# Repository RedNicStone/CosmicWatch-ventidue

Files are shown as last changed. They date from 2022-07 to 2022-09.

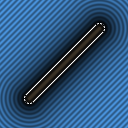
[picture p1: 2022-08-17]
software/arduino/cmake-build-debug/feh_078198_000001_demo.bmp

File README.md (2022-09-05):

<p align="center">
    CosmicWatch logo
    CosmicWatch logo
</p>

---
[]()
[]()
[]()

# CosmicWatch Ventidue
Continuation of the original CosmicWatch project by Spencer featuring many improvements and additions.

## What's new?
CosmicWatch Ventidue's new features are plentiful so here is a quick summary:
- Flexible design that allows connecting either one or two detectors
- Built in on-silicon coincidence detection between the two modules
  - Time resolutions from 5ns down to just 1ns [cooling required]
- Powerful Teensy 4.1 microcontroller
- Full color 1.5" OLED display with great user interface
  - Rotary encoder for easy navigation
  - Buzzer for audible counting and interface feedback
  - Custom rendering library for maximum performance
- Optional solder-free support for multiple prebuilt sensor modules
  - GPS, Pressure, Humidity, Temperature and RTC supported
- Built in Ethernet module for intra & intercommunication
- Improved mechanical stability and 3D printed casing
- Interrupt driven software architecture for accurate counting and a responsive user interface

## Hardware []()
A first prototype has been produced and tested. 
We are currently busy on fabricating a newer board that will be tested as soon as finished.  
There are plans to provide a kit with a pre-assembled board for purchase once hardware development has sized.

### Overview
> todo

## Software []()
Software is currently undergoing heavy development and is only barely runnable.  
If you do want to take a look [check this folder](software/arduino).

The following modules have been written so far:
- Custom rendering pipeline
- OLED driver [Needs push to support DMA]
- On-chip coincidence detection
- Example for testing peripherals

The following modules still need tending:
- True type font rendering
- UI and windowing system
- Data acquisition and storage
- Ethernet communication

**Any help is much appreciated!**

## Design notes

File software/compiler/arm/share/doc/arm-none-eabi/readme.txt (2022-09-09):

Arm GNU Toolchain 12.2.mpacbti-bet1
GNU toolchain for the Arm architecture
GCC Version: 12.2

For updated content, see the release note for the relevant release, on:
https://developer.arm.com/tools-and-software/open-source-software/developer-tools/gnu-toolchain/downloads

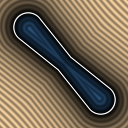
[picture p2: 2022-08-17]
software/arduino/demo.bmp

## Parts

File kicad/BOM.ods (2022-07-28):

Main PCB
Quantity | Name | Value / Part number | Digikey part number
1 | 2x Two way shottky diode, SMD | BAS70XY | 1727-2168-1-ND
1 | 3.6V Linear voltage regulator, SMD | TCR2EF | TCR2EF33LM(CTCT-ND
1 | Active switching boost voltage regulator, SMD | MAX5025 | MAX5026EUT+TCT-ND
8 | Capacitor, SMD, non polarized | 1uF
1 | Capacitor, SMD, non polarized | 10nF
1 | Capacitor, SMD, non polarized | 0.1uF
1 | Inductor, SMD | 47uH / LQH32CN470K53L | 490-4063-1-ND
1 | JST-PH connector, 1x02 pins, 2mm pitch | B2B-PH-K-S(LF)(SN) | 455-1704-ND
1 | Piezo buzzer | PS1240P02BT | 445-2525-1-ND
1 | Pin header, 1x05 pins, 2.45mm pitch | 77311-102-05LF | 609-77311-102-05LF-ND
1 | Pin socket, 1x04 pins, 2.45mm pitch
3 | Pin socket, 1x05 pins, 2.45mm pitch
3 | Pin socket, 1x07 pins, 2.45mm pitch
1 | Pin socket, 1x06 pins, 2.45mm pitch
2 | Resistor, SMD | 10k
3 | Resistor, SMD | 1k
1 | Resistor, SMD | 0
1 | Resistor, SMD | 6.65k
1 | Resistor, SMD | 147k
1 | Resistor, SMD | 100
1 | RJ45 connector with LED indicators | J1B12111CCD | 1278-1052-ND
1 | Shottky diode, SMD | MBR0540 | MBR0540CT-ND
1 | Tennsy 4.1 Micro controller | DEV-16771 | 1568-DEV-16771-ND
SiPM
Quantity | Name | Value / Part number | Digikey part number
1 | 2x Two way shottky diode, SMD | BAS70XY | 1727-2168-1-ND
1 | Capacitor, SMD, non polarized | 1uF
4 | Capacitor, SMD, non polarized | 10nF
2 | Capacitor, SMD, non polarized | 0.1uF
2 | Capacitor, SMD, non polarized | 13pF
2 | Capacitor, SMD, non polarized | 2nF
1 | Pin header, 1x05 pins, SMD, 2.45mm pitch | TSM-105-01-F-SV | TSM-105-01-F-SV-ND
1 | Pin header, 1x07 pins, SMD, 2.45mm pitch | TSM-107-01-L-SV | 2031-TSM-107-01-L-SV-ND
2 | Rail to Rail operational amplifier, SMD | LT1807 | 505-LT1807CMS8#PBF-ND
2 | Resistor, SMD | 50
2 | Resistor, SMD | 150
4 | Resistor, SMD | 100k
2 | Resistor, SMD | 10k
1 | Resistor, SMD | 1k
1 | Resistor, SMD | 10
1 | Resistor, SMD | 2.32k
4 | uFl socket, SMD, vertical | CONUFL001-SMD-T | CONUFL001-SMD-TCT-ND
1 | Silicon cascading photomultiplier | SiPM_MICRORB−60035−MLP | MICROFC-60035-SMT-TR1OS-ND
To order
Quantity | Name | Part number | Digikey part number
3 | 2x Two way shottky diode, SMD | BAS70XY | 1727-2168-1-ND
1 | Piezo buzzer | PS1240P02BT | 445-2525-1-ND
1 | RJ45 connector with LED indicators | J1B12111CCD | 1278-1052-ND
1 | JST-PH connector, 1x02 pins, 2mm pitch | B2B-PH-K-S(LF)(SN) | 455-1704-ND
1 | Pin headers, SMD, 2.54mm pitch | GBC36SABN-M30 | S1033E-36-ND
1 | Pin headers, 2.54mm pitch | PBC36SAAN | S1011E-36-ND
2 | Pin sockets, 2.54mm pitch | SSA-132-S-G | SAM1121-32-ND
1 | Mini GPS PA1010D | 4415 | 1528-4415-ND
4 | Capacitor, SMD, 10nF, 30V
5 | Capacitor, SMD, 1uF, 30V

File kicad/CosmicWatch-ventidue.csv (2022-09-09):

Source: | /home/niels/CLionProjects/CosmicWatch-ventidue/kicad/CosmicWatch-ventidue.kicad_sch
Date: | Wed 07 Sep 2022 05:16:37 PM CEST
Tool: | Eeschema 6.0.7-1.fc36
Generator: | /usr/share/kicad/plugins/bom_csv_grouped_by_value.py
Component Count: | 117
Individual Components:
Item | Qty | Reference(s) | Value | LibPart | Footprint | Datasheet | LCSC | MANUFACTURER | MAXIMUM_PACKAGE_HEIGHT | PARTREV | STANDARD
 |  | BT401 | Battery_Cell | Device:Battery_Cell | Connector_Molex:Molex_PicoBlade_53047-0210_1x02_P1.25mm_Vertical | ~ | C518987
 |  | BZ101 | Buzzer | Device:Buzzer | Buzzer_Beeper:Buzzer_TDK_PS1240P02BT_D12.2mm_H6.5mm | ~ | C76871
 |  | C201 | 10nF | Device:C | Capacitor_SMD:C_0805_2012Metric_Pad1.18x1.45mm_HandSolder | ~ | C24666
 |  | C202 | 0.1uF | Device:C | Capacitor_SMD:C_0805_2012Metric_Pad1.18x1.45mm_HandSolder | ~ | C89258
 |  | C203 | 1uF | Device:C | Capacitor_SMD:C_0805_2012Metric_Pad1.18x1.45mm_HandSolder | ~ | C89190
 |  | C204 | 10nF | Device:C | Capacitor_SMD:C_0805_2012Metric_Pad1.18x1.45mm_HandSolder | ~ | C24666
 |  | C205 | 10nF | Device:C | Capacitor_SMD:C_0805_2012Metric_Pad1.18x1.45mm_HandSolder | ~ | C24666
 |  | C206 | 0.1uF | Device:C | Capacitor_SMD:C_0805_2012Metric_Pad1.18x1.45mm_HandSolder | ~ | C89258
 |  | C207 | 10nF | Device:C | Capacitor_SMD:C_0805_2012Metric_Pad1.18x1.45mm_HandSolder | ~ | C24666
 |  | C208 | 13pF | Device:C | Capacitor_SMD:C_0805_2012Metric_Pad1.18x1.45mm_HandSolder | ~ | C501858
 |  | C209 | 13pF | Device:C | Capacitor_SMD:C_0805_2012Metric_Pad1.18x1.45mm_HandSolder | ~ | C501858
 |  | C210 | 1uF | Device:C | Capacitor_SMD:C_0805_2012Metric_Pad1.18x1.45mm_HandSolder | ~ | C89190
 |  | C211 | 2nF | Device:C | Capacitor_SMD:C_0805_2012Metric_Pad1.18x1.45mm_HandSolder | ~ | C51574
 |  | C212 | 2nF | Device:C | Capacitor_SMD:C_0805_2012Metric_Pad1.18x1.45mm_HandSolder | ~ | C51574
 |  | C301 | 10nF | Device:C | Capacitor_SMD:C_0805_2012Metric_Pad1.18x1.45mm_HandSolder | ~ | C24666
 |  | C302 | 0.1uF | Device:C | Capacitor_SMD:C_0805_2012Metric_Pad1.18x1.45mm_HandSolder | ~ | C89258
 |  | C303 | 1uF | Device:C | Capacitor_SMD:C_0805_2012Metric_Pad1.18x1.45mm_HandSolder | ~ | C89190
 |  | C304 | 10nF | Device:C | Capacitor_SMD:C_0805_2012Metric_Pad1.18x1.45mm_HandSolder | ~ | C24666
 |  | C305 | 10nF | Device:C | Capacitor_SMD:C_0805_2012Metric_Pad1.18x1.45mm_HandSolder | ~ | C24666
 |  | C306 | 0.1uF | Device:C | Capacitor_SMD:C_0805_2012Metric_Pad1.18x1.45mm_HandSolder | ~ | C89258
 |  | C307 | 10nF | Device:C | Capacitor_SMD:C_0805_2012Metric_Pad1.18x1.45mm_HandSolder | ~ | C24666
 |  | C308 | 13pF | Device:C | Capacitor_SMD:C_0805_2012Metric_Pad1.18x1.45mm_HandSolder | ~ | C501858
 |  | C309 | 13pF | Device:C | Capacitor_SMD:C_0805_2012Metric_Pad1.18x1.45mm_HandSolder | ~ | C501858
 |  | C310 | 1uF | Device:C | Capacitor_SMD:C_0805_2012Metric_Pad1.18x1.45mm_HandSolder | ~ | C89190
 |  | C311 | 2nF | Device:C | Capacitor_SMD:C_0805_2012Metric_Pad1.18x1.45mm_HandSolder | ~ | C51574
 |  | C312 | 2nF | Device:C | Capacitor_SMD:C_0805_2012Metric_Pad1.18x1.45mm_HandSolder | ~ | C51574
 |  | C401 | 1uF | Device:C | Capacitor_SMD:C_0805_2012Metric_Pad1.18x1.45mm_HandSolder | ~ | C89190
 |  | C402 | 1uF | Device:C | Capacitor_SMD:C_0805_2012Metric_Pad1.18x1.45mm_HandSolder | ~ | C89190
 |  | C403 | 47uF | Device:C | Capacitor_SMD:C_0805_2012Metric_Pad1.18x1.45mm_HandSolder | ~ | C89190
 |  | C404 | 1uF | Device:C | Capacitor_SMD:C_0805_2012Metric_Pad1.18x1.45mm_HandSolder | ~ | C89190
 |  | C405 | 1uF, 50V | Device:C | Capacitor_SMD:C_0805_2012Metric_Pad1.18x1.45mm_HandSolder | ~ | C111768
 |  | C406 | 1uF, 50V | Device:C | Capacitor_SMD:C_0805_2012Metric_Pad1.18x1.45mm_HandSolder | ~ | C111768
 |  | C407 | 10nF, 50V | Device:C | Capacitor_SMD:C_0805_2012Metric_Pad1.18x1.45mm_HandSolder | ~ | C83170
 |  | C408 | 100nF | Device:C | Capacitor_SMD:C_0805_2012Metric_Pad1.18x1.45mm_HandSolder | ~ | C89190
 |  | C501 | 0.1uF | Device:C | Capacitor_SMD:C_0805_2012Metric_Pad1.18x1.45mm_HandSolder | ~ | C89258
 |  | D101 | BAS70XY | CosmicWatchPro:BAS70XY | CosmicWatchPro:SOT-666 | ~ | C73592
 |  | D201 | SiPM_MICRORB−60035−MLP | CosmicWatchPro:SiPM_MICRORB−10035−MLP | CosmicWatchPro:SiPM_MICROFC-60035-SMT-HANDSOLDER | ~ | C905854
 |  | D202 | BAS70XY | CosmicWatchPro:BAS70XY | CosmicWatchPro:SOT-666 | ~ | C73592
 |  | D301 | SiPM_MICRORB−60035−MLP | CosmicWatchPro:SiPM_MICRORB−10035−MLP | CosmicWatchPro:SiPM_MICROFC-60035-SMT-HANDSOLDER | ~ | C905854
 |  | D302 | BAS70XY | CosmicWatchPro:BAS70XY | CosmicWatchPro:SOT-666 | ~ | C73592
 |  | D401 | D_Schottky | Device:D_Schottky | Diode_SMD:D_SOD-123 | ~ | C1884550
 |  | J101 | Conn_01x05 | Connector_Generic:Conn_01x05 | Connector_PinHeader_2.54mm:PinHeader_1x05_P2.54mm_Vertical_SMD_Pin1Right | ~
 |  | J102 | Conn_01x07 | Connector_Generic:Conn_01x07 | Connector_PinHeader_2.54mm:PinHeader_1x07_P2.54mm_Vertical_SMD_Pin1Right | ~
 |  | J103 | Conn_01x05 | Connector_Generic:Conn_01x05 | Connector_PinHeader_2.54mm:PinHeader_1x05_P2.54mm_Vertical_SMD_Pin1Right | ~
 |  | J104 | Conn_01x07 | Connector_Generic:Conn_01x07 | Connector_PinHeader_2.54mm:PinHeader_1x07_P2.54mm_Vertical_SMD_Pin1Right | ~
 |  | J105 | Conn_01x05 | Connector_Generic:Conn_01x05 | Connector_PinSocket_2.54mm:PinSocket_1x05_P2.54mm_Vertical | ~
 |  | J106 | Conn_01x07 | Connector_Generic:Conn_01x07 | Connector_PinSocket_2.54mm:PinSocket_1x07_P2.54mm_Vertical | ~
 |  | J107 | Conn_01x05 | Connector_Generic:Conn_01x05 | Connector_PinSocket_2.54mm:PinSocket_1x05_P2.54mm_Vertical | ~
 |  | J108 | Conn_01x07 | Connector_Generic:Conn_01x07 | Connector_PinSocket_2.54mm:PinSocket_1x07_P2.54mm_Vertical | ~
 |  | J109 | BMP280 | Connector_Generic:Conn_01x04 | Connector_PinSocket_2.54mm:PinSocket_1x04_P2.54mm_Vertical | ~
 |  | J110 | Mini GPS | Connector_Generic:Conn_01x06 | Connector_PinSocket_2.54mm:PinSocket_1x06_P2.54mm_Vertical | ~
 |  | J111 | OLED | Connector_Generic:Conn_01x07 | Connector_PinSocket_2.54mm:PinSocket_1x07_P2.54mm_Vertical | ~
 |  | J112 | DS3231 | Connector_Generic:Conn_01x05 | Connector_PinHeader_2.54mm:PinHeader_1x05_P2.54mm_Vertical | ~
 |  | J201 | Conn_SMA | CosmicWatchPro:Conn_SMA | Connector_Coaxial:U.FL_Molex_MCRF_73412-0110_Vertical | ~ | C88374
 |  | J202 | Conn_SMA | CosmicWatchPro:Conn_SMA | Connector_Coaxial:U.FL_Molex_MCRF_73412-0110_Vertical | ~ | C88374
 |  | J203 | Conn_SMA | CosmicWatchPro:Conn_SMA | Connector_Coaxial:U.FL_Molex_MCRF_73412-0110_Vertical | ~ | C88374
 |  | J204 | Conn_SMA | CosmicWatchPro:Conn_SMA | Connector_Coaxial:U.FL_Molex_MCRF_73412-0110_Vertical | ~ | C88374
 |  | J301 | Conn_SMA | CosmicWatchPro:Conn_SMA | Connector_Coaxial:U.FL_Molex_MCRF_73412-0110_Vertical | ~ | C88374
 |  | J302 | Conn_SMA | CosmicWatchPro:Conn_SMA | Connector_Coaxial:U.FL_Molex_MCRF_73412-0110_Vertical | ~ | C88374
 |  | J303 | Conn_SMA | CosmicWatchPro:Conn_SMA | Connector_Coaxial:U.FL_Molex_MCRF_73412-0110_Vertical | ~ | C88374
 |  | J304 | Conn_SMA | CosmicWatchPro:Conn_SMA | Connector_Coaxial:U.FL_Molex_MCRF_73412-0110_Vertical | ~ | C88374
 |  | J401 | Conn_01x02 | Connector_Generic:Conn_01x02 | Connector_JST:JST_PH_B2B-PH-K_1x02_P2.00mm_Vertical | ~ | C225240
 |  | L401 | 47uH | Device:L | Inductor_SMD:L_1210_3225Metric_Pad1.42x2.65mm_HandSolder | ~ | C113070
 |  | R102 | 1k | Device:R | Resistor_SMD:R_0805_2012Metric_Pad1.20x1.40mm_HandSolder | ~ | C17513
 |  | R105 | 10k | Device:R | Resistor_SMD:R_0805_2012Metric_Pad1.20x1.40mm_HandSolder | ~ | C17414
 |  | R106 | 10k | Device:R | Resistor_SMD:R_0805_2012Metric_Pad1.20x1.40mm_HandSolder | ~ | C17414
 |  | R201 | 50 | Device:R | Resistor_SMD:R_0805_2012Metric_Pad1.20x1.40mm_HandSolder | ~ | C2828807
 |  | R202 | 50 | Device:R | Resistor_SMD:R_0805_2012Metric_Pad1.20x1.40mm_HandSolder | ~ | C2828807
 |  | R203 | 10 | Device:R | Resistor_SMD:R_0805_2012Metric_Pad1.20x1.40mm_HandSolder | ~ | C96347
 |  | R204 | 150 | Device:R | Resistor_SMD:R_0805_2012Metric_Pad1.20x1.40mm_HandSolder | ~ | C17471
 |  | R205 | 2.32k | Device:R | Resistor_SMD:R_0805_2012Metric_Pad1.20x1.40mm_HandSolder | ~ | C17522
 |  | R206 | 10k | Device:R | Resistor_SMD:R_0805_2012Metric_Pad1.20x1.40mm_HandSolder | ~ | C17414
 |  | R207 | 150 | Device:R | Resistor_SMD:R_0805_2012Metric_Pad1.20x1.40mm_HandSolder | ~ | C17471
 |  | R208 | 1k | Device:R | Resistor_SMD:R_0805_2012Metric_Pad1.20x1.40mm_HandSolder | ~ | C17513
 |  | R209 | 100k | Device:R | Resistor_SMD:R_0805_2012Metric_Pad1.20x1.40mm_HandSolder | ~ | C149504
 |  | R210 | 10k | Device:R | Resistor_SMD:R_0805_2012Metric_Pad1.20x1.40mm_HandSolder | ~ | C17414
 |  | R211 | 100k | Device:R | Resistor_SMD:R_0805_2012Metric_Pad1.20x1.40mm_HandSolder | ~ | C149504
 |  | R212 | 100k | Device:R | Resistor_SMD:R_0805_2012Metric_Pad1.20x1.40mm_HandSolder | ~ | C149504
 |  | R213 | 100k | Device:R | Resistor_SMD:R_0805_2012Metric_Pad1.20x1.40mm_HandSolder | ~ | C149504
 |  | R301 | 50 | Device:R | Resistor_SMD:R_0805_2012Metric_Pad1.20x1.40mm_HandSolder | ~ | C2828807
 |  | R302 | 50 | Device:R | Resistor_SMD:R_0805_2012Metric_Pad1.20x1.40mm_HandSolder | ~ | C2828807
 |  | R303 | 10 | Device:R | Resistor_SMD:R_0805_2012Metric_Pad1.20x1.40mm_HandSolder | ~ | C96347
 |  | R304 | 150 | Device:R | Resistor_SMD:R_0805_2012Metric_Pad1.20x1.40mm_HandSolder | ~ | C17471
 |  | R305 | 2.32k | Device:R | Resistor_SMD:R_0805_2012Metric_Pad1.20x1.40mm_HandSolder | ~ | C17522
 |  | R306 | 10k | Device:R | Resistor_SMD:R_0805_2012Metric_Pad1.20x1.40mm_HandSolder | ~ | C17414
 |  | R307 | 150 | Device:R | Resistor_SMD:R_0805_2012Metric_Pad1.20x1.40mm_HandSolder | ~ | C17471
 |  | R308 | 1k | Device:R | Resistor_SMD:R_0805_2012Metric_Pad1.20x1.40mm_HandSolder | ~ | C17513
 |  | R309 | 100k | Device:R | Resistor_SMD:R_0805_2012Metric_Pad1.20x1.40mm_HandSolder | ~ | C149504
 |  | R310 | 10k | Device:R | Resistor_SMD:R_0805_2012Metric_Pad1.20x1.40mm_HandSolder | ~ | C17414
 |  | R311 | 100k | Device:R | Resistor_SMD:R_0805_2012Metric_Pad1.20x1.40mm_HandSolder | ~ | C149504
 |  | R312 | 100k | Device:R | Resistor_SMD:R_0805_2012Metric_Pad1.20x1.40mm_HandSolder | ~ | C149504
 |  | R313 | 100k | Device:R | Resistor_SMD:R_0805_2012Metric_Pad1.20x1.40mm_HandSolder | ~ | C149504
 |  | R401 | 6.8k | Device:R | Resistor_SMD:R_0805_2012Metric_Pad1.20x1.40mm_HandSolder | ~ | C17770
 |  | R402 | 150k | Device:R | Resistor_SMD:R_0805_2012Metric_Pad1.20x1.40mm_HandSolder | ~ | C17462
 |  | R403 | 100 | Device:R | Resistor_SMD:R_0805_2012Metric_Pad1.20x1.40mm_HandSolder | ~ | C17408
 |  | R404 | 3.3k | Device:R | Resistor_SMD:R_0805_2012Metric_Pad1.20x1.40mm_HandSolder | ~ | C17770
 |  | SW101 | Digital_Rotary_Encoder_Switch | CosmicWatchPro:Digital_Rotary_Encoder_Switch | Connector_PinSocket_2.54mm:PinSocket_1x05_P2.54mm_Vertical | ~
 |  | TP201 | AMP_{1} | Connector:TestPoint | TestPoint:TestPoint_Pad_D2.0mm | ~
 |  | TP202 | AMP_{2} | Connector:TestPoint | TestPoint:TestPoint_Pad_D2.0mm | ~
 |  | TP203 | GND | Connector:TestPoint | TestPoint:TestPoint_Pad_3.0x3.0mm | ~
 |  | TP301 | AMP_{1} | Connector:TestPoint | TestPoint:TestPoint_Pad_D2.0mm | ~
 |  | TP302 | AMP_{2} | Connector:TestPoint | TestPoint:TestPoint_Pad_D2.0mm | ~
 |  | TP303 | GND | Connector:TestPoint | TestPoint:TestPoint_Pad_3.0x3.0mm | ~
 |  | TP401 | TestPoint | Connector:TestPoint | TestPoint:TestPoint_Pad_3.0x3.0mm | ~
 |  | TP402 | TestPoint | Connector:TestPoint | TestPoint:TestPoint_Pad_D2.0mm | ~
 |  | TP403 | TestPoint | Connector:TestPoint | TestPoint:TestPoint_Pad_D2.0mm | ~
 |  | TP404 | TestPoint | Connector:TestPoint | TestPoint:TestPoint_Pad_D2.0mm | ~
 |  | TP405 | TestPoint | Connector:TestPoint | TestPoint:TestPoint_Pad_D2.0mm | ~
 |  | TP406 | TestPoint | Connector:TestPoint | TestPoint:TestPoint_Pad_D2.0mm | ~
 |  | U101 | Teensy4.1 | CosmicWatchPro:Teensy4.1_minimal | CosmicWatchPro:Teensy4.1_Minimal |  |  | SparkFun Electronics | 4.07mm | 4.1 | Manufacturer recommendations
 |  | U201 | LT1807 | LT1807IMS8PBF:LT1807 | Package_SO:SO-8_3.9x4.9mm_P1.27mm |  | C665379
 |  | U202 | LT1807 | LT1807IMS8PBF:LT1807 | Package_SO:SO-8_3.9x4.9mm_P1.27mm |  | C665379
 |  | U301 | LT1807 | LT1807IMS8PBF:LT1807 | Package_SO:SO-8_3.9x4.9mm_P1.27mm |  | C665379
 |  | U302 | LT1807 | LT1807IMS8PBF:LT1807 | Package_SO:SO-8_3.9x4.9mm_P1.27mm |  | C665379
 |  | U401 | TCR2EF | CosmicWatchPro:TCR2EF | Package_TO_SOT_SMD:SOT-23-5_HandSoldering | https://www.torexsemi.com/file/xc6220/XC6220.pdf
 |  | U402 | MAX5026 | CosmicWatchPro:MAX5025 | Package_TO_SOT_SMD:TSOT-23-6_HandSoldering | https://datasheets.maximintegrated.com/en/ds/MAX5025-MAX5028.pdf | C87603
 |  | U501 | J1B12111CCD | CosmicWatchPro:LPJ4012AHNL | Connector_RJ:RJ45_Cetus_J1B1211CCD_Horizontal
Collated Components:
Item | Qty | Reference(s) | Value | LibPart | Footprint | Datasheet | LCSC | MANUFACTURER | MAXIMUM_PACKAGE_HEIGHT | PARTREV | STANDARD
1 | 1 | BT401 | Battery_Cell | Device:Battery_Cell | Connector_Molex:Molex_PicoBlade_53047-0210_1x02_P1.25mm_Vertical | ~ | C518987
2 | 1 | BZ101 | Buzzer | Device:Buzzer | Buzzer_Beeper:Buzzer_TDK_PS1240P02BT_D12.2mm_H6.5mm | ~ | C76871
3 | 8 | C201, C204, C205, C207, C301, C304, C305, C307 | 10nF | Device:C | Capacitor_SMD:C_0805_2012Metric_Pad1.18x1.45mm_HandSolder | ~ | C24666
4 | 5 | C202, C206, C302, C306, C501 | 0.1uF | Device:C | Capacitor_SMD:C_0805_2012Metric_Pad1.18x1.45mm_HandSolder | ~ | C89258
5 | 7 | C203, C210, C303, C310, C401, C402, C404 | 1uF | Device:C | Capacitor_SMD:C_0805_2012Metric_Pad1.18x1.45mm_HandSolder | ~ | C89190
6 | 4 | C208, C209, C308, C309 | 13pF | Device:C | Capacitor_SMD:C_0805_2012Metric_Pad1.18x1.45mm_HandSolder | ~ | C501858
7 | 4 | C211, C212, C311, C312 | 2nF | Device:C | Capacitor_SMD:C_0805_2012Metric_Pad1.18x1.45mm_HandSolder | ~ | C51574
8 | 1 | C403 | 47uF | Device:C | Capacitor_SMD:C_0805_2012Metric_Pad1.18x1.45mm_HandSolder | ~ | C89190
9 | 2 | C405, C406 | 1uF, 50V | Device:C | Capacitor_SMD:C_0805_2012Metric_Pad1.18x1.45mm_HandSolder | ~ | C111768
10 | 1 | C407 | 10nF, 50V | Device:C | Capacitor_SMD:C_0805_2012Metric_Pad1.18x1.45mm_HandSolder | ~ | C83170
11 | 1 | C408 | 100nF | Device:C | Capacitor_SMD:C_0805_2012Metric_Pad1.18x1.45mm_HandSolder | ~ | C89190
12 | 3 | D101, D202, D302 | BAS70XY | CosmicWatchPro:BAS70XY | CosmicWatchPro:SOT-666 | ~ | C73592
13 | 2 | D201, D301 | SiPM_MICRORB−60035−MLP | CosmicWatchPro:SiPM_MICRORB−10035−MLP | CosmicWatchPro:SiPM_MICROFC-60035-SMT-HANDSOLDER | ~ | C905854
14 | 1 | D401 | D_Schottky | Device:D_Schottky | Diode_SMD:D_SOD-123 | ~ | C1884550
15 | 2 | J101, J103 | Conn_01x05 | Connector_Generic:Conn_01x05 | Connector_PinHeader_2.54mm:PinHeader_1x05_P2.54mm_Vertical_SMD_Pin1Right | ~
16 | 2 | J102, J104 | Conn_01x07 | Connector_Generic:Conn_01x07 | Connector_PinHeader_2.54mm:PinHeader_1x07_P2.54mm_Vertical_SMD_Pin1Right | ~
17 | 2 | J105, J107 | Conn_01x05 | Connector_Generic:Conn_01x05 | Connector_PinSocket_2.54mm:PinSocket_1x05_P2.54mm_Vertical | ~
18 | 2 | J106, J108 | Conn_01x07 | Connector_Generic:Conn_01x07 | Connector_PinSocket_2.54mm:PinSocket_1x07_P2.54mm_Vertical | ~
19 | 1 | J109 | BMP280 | Connector_Generic:Conn_01x04 | Connector_PinSocket_2.54mm:PinSocket_1x04_P2.54mm_Vertical | ~
20 | 1 | J110 | Mini GPS | Connector_Generic:Conn_01x06 | Connector_PinSocket_2.54mm:PinSocket_1x06_P2.54mm_Vertical | ~
21 | 1 | J111 | OLED | Connector_Generic:Conn_01x07 | Connector_PinSocket_2.54mm:PinSocket_1x07_P2.54mm_Vertical | ~
22 | 1 | J112 | DS3231 | Connector_Generic:Conn_01x05 | Connector_PinHeader_2.54mm:PinHeader_1x05_P2.54mm_Vertical | ~
23 | 8 | J201, J202, J203, J204, J301, J302, J303, J304 | Conn_SMA | CosmicWatchPro:Conn_SMA | Connector_Coaxial:U.FL_Molex_MCRF_73412-0110_Vertical | ~ | C88374
24 | 1 | J401 | Conn_01x02 | Connector_Generic:Conn_01x02 | Connector_JST:JST_PH_B2B-PH-K_1x02_P2.00mm_Vertical | ~ | C225240
25 | 1 | L401 | 47uH | Device:L | Inductor_SMD:L_1210_3225Metric_Pad1.42x2.65mm_HandSolder | ~ | C113070
26 | 3 | R102, R208, R308 | 1k | Device:R | Resistor_SMD:R_0805_2012Metric_Pad1.20x1.40mm_HandSolder | ~ | C17513
27 | 6 | R105, R106, R206, R210, R306, R310 | 10k | Device:R | Resistor_SMD:R_0805_2012Metric_Pad1.20x1.40mm_HandSolder | ~ | C17414
28 | 4 | R201, R202, R301, R302 | 50 | Device:R | Resistor_SMD:R_0805_2012Metric_Pad1.20x1.40mm_HandSolder | ~ | C2828807
29 | 2 | R203, R303 | 10 | Device:R | Resistor_SMD:R_0805_2012Metric_Pad1.20x1.40mm_HandSolder | ~ | C96347
30 | 4 | R204, R207, R304, R307 | 150 | Device:R | Resistor_SMD:R_0805_2012Metric_Pad1.20x1.40mm_HandSolder | ~ | C17471
31 | 2 | R205, R305 | 2.32k | Device:R | Resistor_SMD:R_0805_2012Metric_Pad1.20x1.40mm_HandSolder | ~ | C17522
32 | 8 | R209, R211, R212, R213, R309, R311, R312, R313 | 100k | Device:R | Resistor_SMD:R_0805_2012Metric_Pad1.20x1.40mm_HandSolder | ~ | C149504
33 | 1 | R401 | 6.8k | Device:R | Resistor_SMD:R_0805_2012Metric_Pad1.20x1.40mm_HandSolder | ~ | C17770
34 | 1 | R402 | 150k | Device:R | Resistor_SMD:R_0805_2012Metric_Pad1.20x1.40mm_HandSolder | ~ | C17462
35 | 1 | R403 | 100 | Device:R | Resistor_SMD:R_0805_2012Metric_Pad1.20x1.40mm_HandSolder | ~ | C17408
36 | 1 | R404 | 3.3k | Device:R | Resistor_SMD:R_0805_2012Metric_Pad1.20x1.40mm_HandSolder | ~ | C17770
37 | 1 | SW101 | Digital_Rotary_Encoder_Switch | CosmicWatchPro:Digital_Rotary_Encoder_Switch | Connector_PinSocket_2.54mm:PinSocket_1x05_P2.54mm_Vertical | ~
38 | 2 | TP201, TP301 | AMP_{1} | Connector:TestPoint | TestPoint:TestPoint_Pad_D2.0mm | ~
39 | 2 | TP202, TP302 | AMP_{2} | Connector:TestPoint | TestPoint:TestPoint_Pad_D2.0mm | ~
40 | 2 | TP203, TP303 | GND | Connector:TestPoint | TestPoint:TestPoint_Pad_3.0x3.0mm | ~
41 | 1 | TP401 | TestPoint | Connector:TestPoint | TestPoint:TestPoint_Pad_3.0x3.0mm | ~
42 | 5 | TP402, TP403, TP404, TP405, TP406 | TestPoint | Connector:TestPoint | TestPoint:TestPoint_Pad_D2.0mm | ~
43 | 1 | U101 | Teensy4.1 | CosmicWatchPro:Teensy4.1_minimal | CosmicWatchPro:Teensy4.1_Minimal |  |  | SparkFun Electronics | 4.07mm | 4.1 | Manufacturer recommendations
44 | 4 | U201, U202, U301, U302 | LT1807 | LT1807IMS8PBF:LT1807 | Package_SO:SO-8_3.9x4.9mm_P1.27mm |  | C665379
45 | 1 | U401 | TCR2EF | CosmicWatchPro:TCR2EF | Package_TO_SOT_SMD:SOT-23-5_HandSoldering | https://www.torexsemi.com/file/xc6220/XC6220.pdf
46 | 1 | U402 | MAX5026 | CosmicWatchPro:MAX5025 | Package_TO_SOT_SMD:TSOT-23-6_HandSoldering | https://datasheets.maximintegrated.com/en/ds/MAX5025-MAX5028.pdf | C87603
47 | 1 | U501 | J1B12111CCD | CosmicWatchPro:LPJ4012AHNL | Connector_RJ:RJ45_Cetus_J1B1211CCD_Horizontal

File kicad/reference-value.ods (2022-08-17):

Reference(s) | Value | Reference(s) | Value | Reference(s) | Value
BT401 | Battery_Cell | D401 | D_Schottky | R213 | 100k
BZ101 | Buzzer | J101 | Conn_01x05 | R301 | 50
C201 | 10nF | J102 | Conn_01x07 | R302 | 50
C202 | 0.1uF | J103 | Conn_01x05 | R303 | 10
C203 | 1uF | J104 | Conn_01x07 | R304 | 150
C204 | 10nF | J105 | Conn_01x05 | R305 | 2.32k
C205 | 10nF | J106 | Conn_01x07 | R306 | 10k
C206 | 0.1uF | J107 | Conn_01x05 | R307 | 150
C207 | 10nF | J108 | Conn_01x07 | R308 | 1k
C208 | 13pF | J109 | BMP280 | R309 | 100k
C209 | 13pF | J110 | Mini GPS | R310 | 10k
C210 | 1uF | J111 | OLED | R311 | 100k
C211 | 2nF | J112 | DS3231 | R312 | 100k
C212 | 2nF | J201 | Conn_SMA | R313 | 100k
C301 | 10nF | J202 | Conn_SMA | R401 | 6.65k
C302 | 0.1uF | J203 | Conn_SMA | R402 | 147k
C303 | 1uF | J204 | Conn_SMA | R403 | 100
C304 | 10nF | J301 | Conn_SMA | SW101 | Rotary_Encoder
C305 | 10nF | J302 | Conn_SMA | TP201 | AMP_{1}
C306 | 0.1uF | J303 | Conn_SMA | TP202 | AMP_{2}
C307 | 10nF | J304 | Conn_SMA | TP203 | GND
C308 | 13pF | J401 | Conn_01x02 | TP301 | AMP_{1}
C309 | 13pF | L401 | 47uH | TP302 | AMP_{2}
C310 | 1uF | R102 | 1k | TP303 | GND
C311 | 2nF | R105 | 10k | TP401 | TestPoint
C312 | 2nF | R106 | 10k | TP402 | TestPoint
C401 | 1uF | R201 | 50 | TP403 | TestPoint
C402 | 1uF | R202 | 50 | TP404 | TestPoint
C403 | 1uF | R203 | 10 | TP405 | TestPoint
C404 | 1uF | R204 | 150 | TP406 | TestPoint
C405 | 1uF, 50V | R205 | 2.32k | U101 | Teensy4.1
C406 | 1uF, 50V | R206 | 10k | U201 | LT1807
C407 | 10nF, 50V | R207 | 150 | U202 | LT1807
C501 | 0.1uF | R208 | 1k | U301 | LT1807
D101 | BAS70XY | R209 | 100k | U302 | LT1807
D201 | SiPM | R210 | 10k | U401 | TCR2EF
D202 | BAS70XY | R211 | 100k | U402 | MAX5026
D301 | SiPM | R212 | 100k | U501 | J1B12111CCD
D302 | BAS70XY

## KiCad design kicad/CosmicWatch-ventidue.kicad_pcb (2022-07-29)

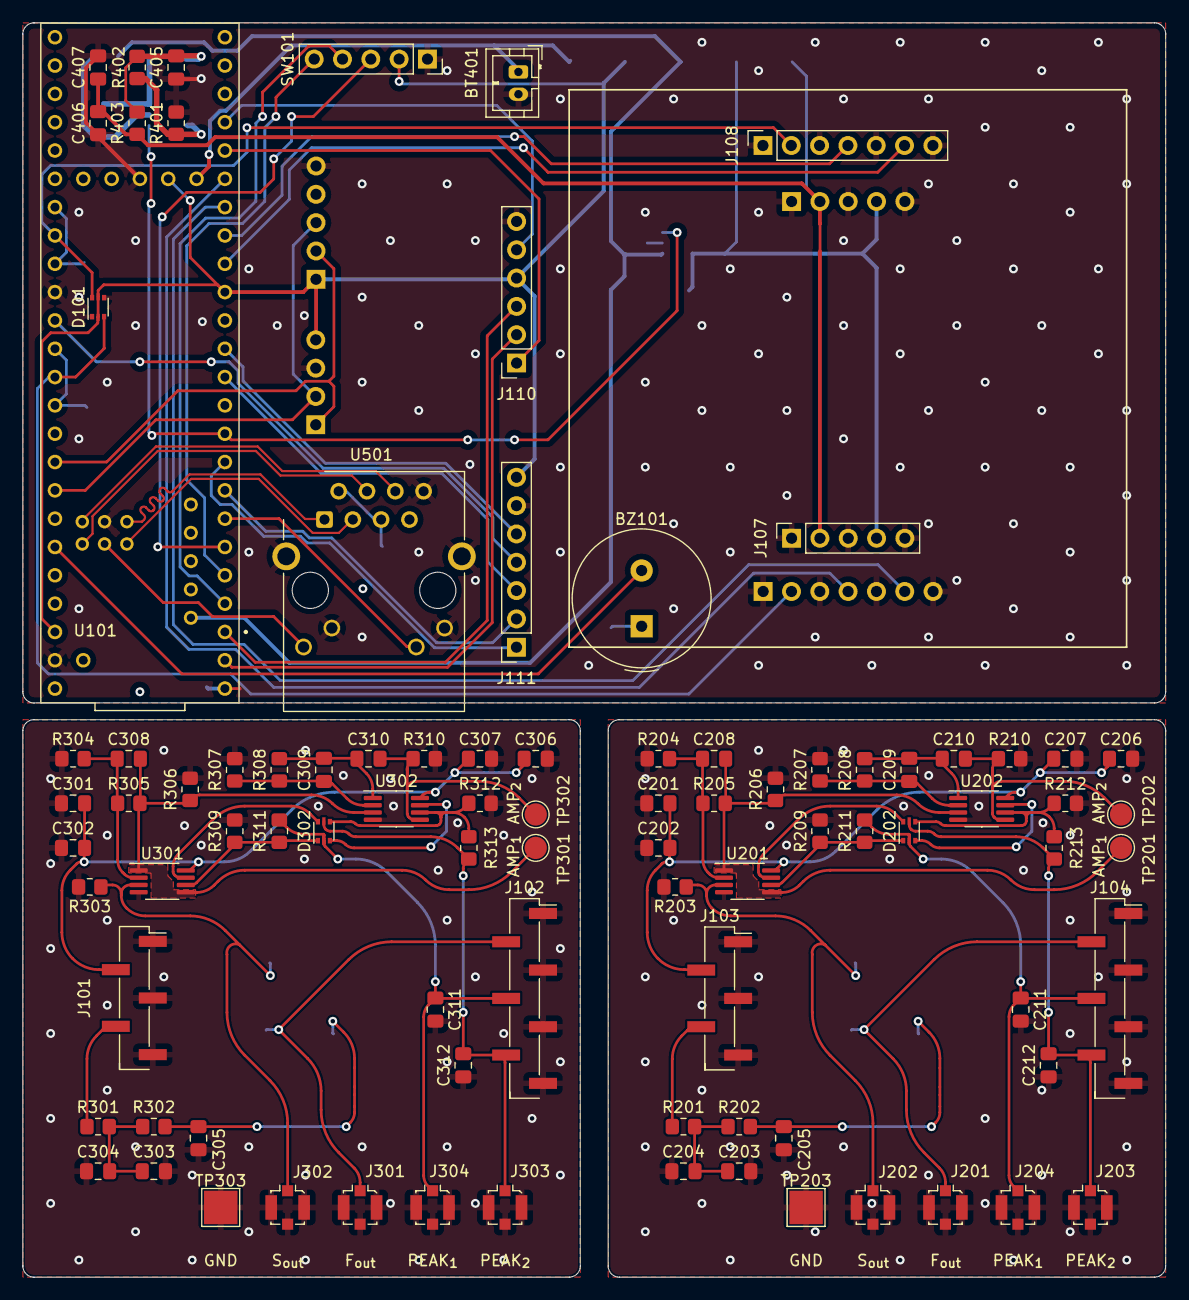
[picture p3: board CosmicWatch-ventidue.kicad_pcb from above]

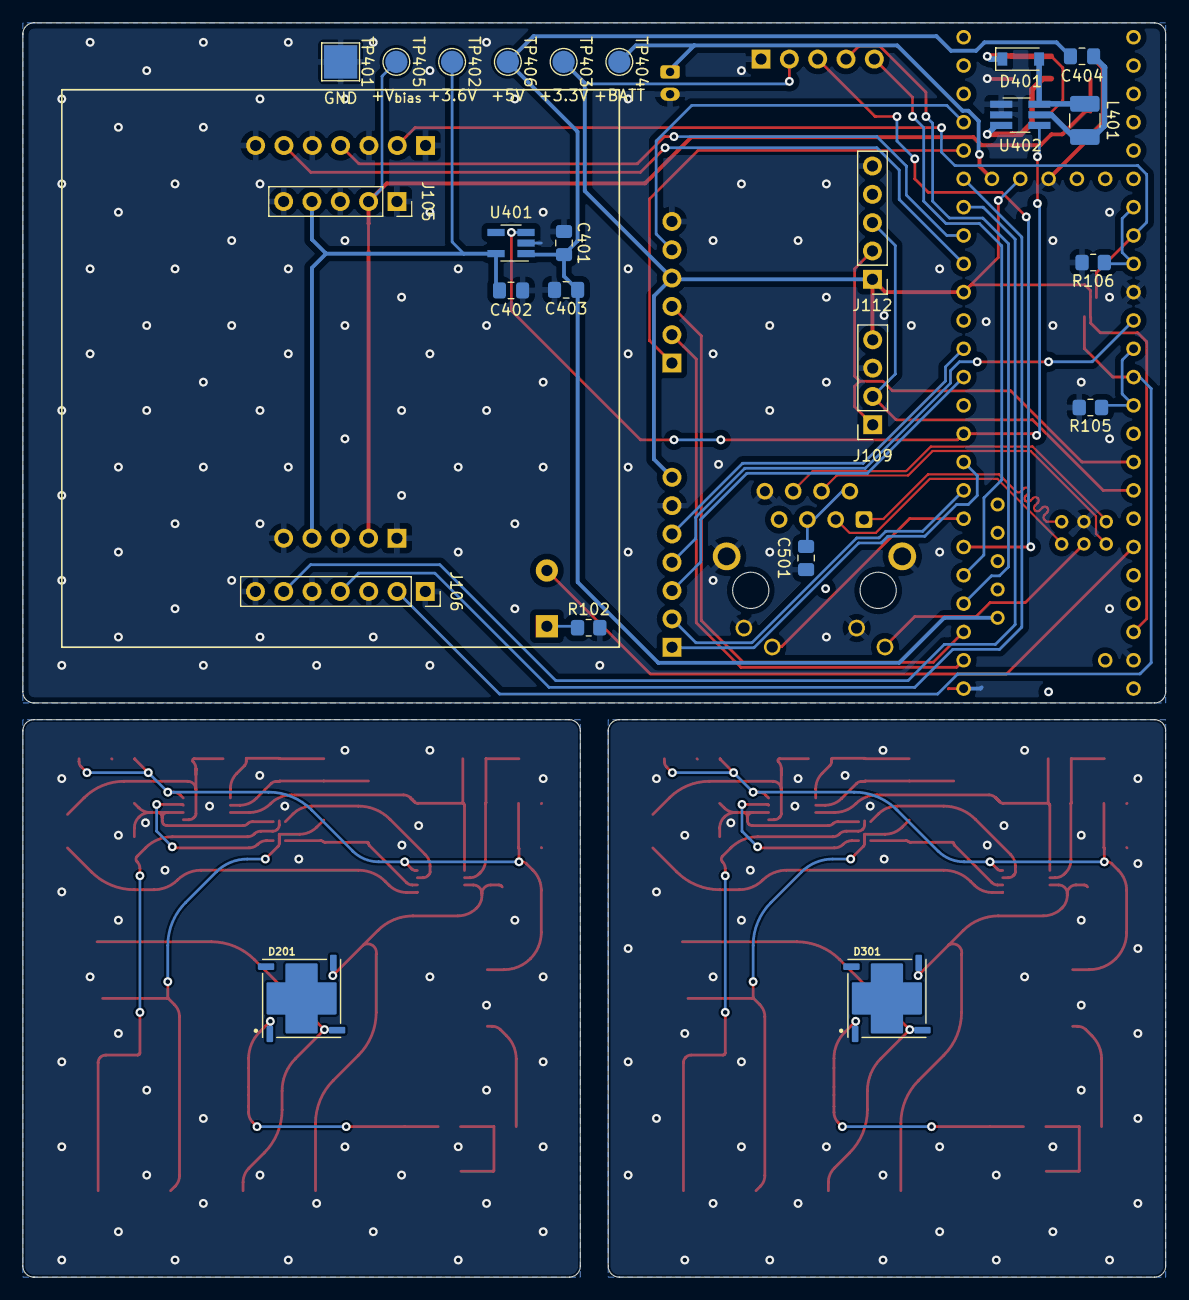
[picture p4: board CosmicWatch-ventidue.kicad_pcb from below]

Board: 2 copper layers, 102.5 x 112.5 mm, 114 parts (24 on the bottom side), 78 nets.

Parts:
BT401: Battery_Cell; JST_PH_B2B-PH-K_1x02_P2.00mm_Vertical
BZ101: Buzzer; Buzzer_TDK_PS1240P02BT_D12.2mm_H6.5mm
C201, C204, C205, C207, C301, C304, C305, C307, C407: 10nF; C_0805_2012Metric_Pad1.18x1.45mm_HandSolder
C202, C206, C302, C306, C501: 0.1uF; C_0805_2012Metric_Pad1.18x1.45mm_HandSolder
C203, C210, C303, C310, C401, C402, C403, C404, C405, C406: 1uF; C_0805_2012Metric_Pad1.18x1.45mm_HandSolder
C208, C209, C308, C309: 13pF; C_0805_2012Metric_Pad1.18x1.45mm_HandSolder
C211, C212, C311, C312: 2nF; C_0805_2012Metric_Pad1.18x1.45mm_HandSolder
D101, D202, D302: BAS70XY; SOT-666
D201, D301: SiPM_MICRORB−60035−MLP; SiPM_MICROFC-60035-SMT-HANDSOLDER
D401: D_Schottky; D_SOD-123
J101, J103: Conn_01x05; PinHeader_1x05_P2.54mm_Vertical_SMD_Pin1Right
J102, J104: Conn_01x07; PinHeader_1x07_P2.54mm_Vertical_SMD_Pin1Right
J105, J107: Conn_01x05; PinSocket_1x05_P2.54mm_Vertical
J106, J108: Conn_01x07; PinSocket_1x07_P2.54mm_Vertical
J109: BMP280; PinSocket_1x04_P2.54mm_Vertical
J110: Conn_01x06; PinSocket_1x06_P2.54mm_Vertical
J111: OLED; PinSocket_1x07_P2.54mm_Vertical
J112: DS3231; PinHeader_1x05_P2.54mm_Vertical
J201, J202, J203, J204, J301, J302, J303, J304: Conn_SMA; U.FL_Molex_MCRF_73412-0110_Vertical
L401: 47uH; L_1210_3225Metric_Pad1.42x2.65mm_HandSolder
R102, R208, R308: 1k; R_0805_2012Metric_Pad1.20x1.40mm_HandSolder
R105, R106, R206, R210, R306, R310: 10k; R_0805_2012Metric_Pad1.20x1.40mm_HandSolder
R201, R202, R301, R302: 50; R_0805_2012Metric_Pad1.20x1.40mm_HandSolder
R203, R303: 10; R_0805_2012Metric_Pad1.20x1.40mm_HandSolder
R204, R207, R304, R307: 150; R_0805_2012Metric_Pad1.20x1.40mm_HandSolder
R205, R305: 2.32k; R_0805_2012Metric_Pad1.20x1.40mm_HandSolder
R209, R211, R212, R213, R309, R311, R312, R313: 100k; R_0805_2012Metric_Pad1.20x1.40mm_HandSolder
R401: 6.65k; R_0805_2012Metric_Pad1.20x1.40mm_HandSolder
R402: 147k; R_0805_2012Metric_Pad1.20x1.40mm_HandSolder
R403: 100; R_0805_2012Metric_Pad1.20x1.40mm_HandSolder
SW101: Digital_Rotary_Encoder_Switch; PinSocket_1x05_P2.54mm_Vertical
TP201, TP301: AMP_{1}; TestPoint_Pad_D2.0mm
TP202, TP302: AMP_{2}; TestPoint_Pad_D2.0mm
TP203, TP303: GND; TestPoint_Pad_3.0x3.0mm
TP401: TestPoint; TestPoint_Pad_3.0x3.0mm
TP402, TP403, TP404, TP405, TP406: TestPoint; TestPoint_Pad_D2.0mm
U101: Teensy4.1
U201, U202, U301, U302: LT1807; MSOP-8_3x3mm_P0.65mm
U401: TCR2EF; SOT-23-5_HandSoldering
U402: MAX5025; TSOT-23-6_HandSoldering
U501: J1B12111CCD; RJ45_Cetus_J1B1211CCD_Horizontal

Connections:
+3.3V: D101.2 (K), D101.5 (K), J109.4, J110.4, J111.7, J112.1, SW101.2 (VCC), TP403.1, U101.3.3V_1 (3.3V), U101.3.3V_2 (3.3V__1), U101.3.3V_3 (3.3V__2)
+3.6V: C402.1, J105.4, J107.4, TP402.1, U401.5 (VOUT)
+5V: C401.1, C403.1, C404.1, TP406.1, U101.5V, U401.1 (VIN)
+BATT: BT401.1 (+), TP404.1, U101.VBAT
+V_{bias}: C406.1, C407.1, J105.2, J107.2, R403.2, TP405.1
/Buzzer: BZ101.2 (+), U101.21 (A7)
/D_{1}-F: D101.3 (common), J106.2, U101.15 (A1)
/D_{1}-P_{1}: J106.4, U101.27 (A13)
/D_{1}-P_{2}: J106.6, U101.26 (A12)
/D_{2}-F: D101.6 (common), J108.2, U101.40 (A16)
/D_{2}-P_{1}: J108.4, U101.25 (A11)
/D_{2}-P_{2}: J108.6, U101.24 (A10)
/Detector PCB 1/+3.6V: C301.1, C302.1, C306.1, C307.1, J101.2, U301.8 (V+), U302.8 (V+)
/Detector PCB 1/AMP_{1}: C308.2, R305.2, R306.1, TP301.1, U301.1, U301.5 (+), U302.3 (+)
/Detector PCB 1/AMP_{2}: C310.2, R310.1, TP302.1, U302.5 (+)
/Detector PCB 1/F_{out}: D301.2 (Fast_Output), J102.2, J301.1 (In)
/Detector PCB 1/GND: C301.2, C302.2, C303.2, C304.2, C305.2, C306.2, C307.2, C311.2, C312.2, J101.1, J101.3, J101.5, J102.1, J102.3, J102.5, J102.7, J301.2 (Ext), J302.2 (Ext), J303.2 (Ext), J304.2 (Ext), R303.2, R304.2, R306.2, R307.2, R309.2, R310.2, R312.2, TP303.1, U301.4 (V-), U302.4 (V-)
/Detector PCB 1/PEAK_{1}: C311.1, D302.2 (K), J102.4, J304.1 (In), R311.2
/Detector PCB 1/PEAK_{2}: C312.1, D302.5 (K), J102.6, J303.1 (In), R313.2
/Detector PCB 1/S_{out}: D301.3 (Cathode), J302.1 (In), R303.1, U301.3 (+)
/Detector PCB 1/V_{bias}: J101.4, R301.1
/Detector PCB 2/+3.6V: C201.1, C202.1, C206.1, C207.1, J103.2, U201.8 (V+), U202.8 (V+)
/Detector PCB 2/AMP_{1}: C208.2, R205.2, R206.1, TP201.1, U201.1, U201.5 (+), U202.3 (+)
/Detector PCB 2/AMP_{2}: C210.2, R210.1, TP202.1, U202.5 (+)
/Detector PCB 2/F_{out}: D201.2 (Fast_Output), J104.2, J201.1 (In)
/Detector PCB 2/GND: C201.2, C202.2, C203.2, C204.2, C205.2, C206.2, C207.2, C211.2, C212.2, J103.1, J103.3, J103.5, J104.1, J104.3, J104.5, J104.7, J201.2 (Ext), J202.2 (Ext), J203.2 (Ext), J204.2 (Ext), R203.2, R204.2, R206.2, R207.2, R209.2, R210.2, R212.2, TP203.1, U201.4 (V-), U202.4 (V-)
/Detector PCB 2/PEAK_{1}: C211.1, D202.2 (K), J104.4, J204.1 (In), R211.2
/Detector PCB 2/PEAK_{2}: C212.1, D202.5 (K), J104.6, J203.1 (In), R213.2
/Detector PCB 2/S_{out}: D201.3 (Cathode), J202.1 (In), R203.1, U201.3 (+)
/Detector PCB 2/V_{bias}: J103.4, R201.1
/Eth-LED_{1}: U101.LED, U501.9 (LLED+)
/Eth-LED_{2}: U101.5 (IN2), U501.11 (RLED+)
/Eth-RX+: U101.R+, U501.4 (TD-)
/Eth-RX-: U101.R-, U501.6 (TD+)
/Eth-TX+: U101.T+, U501.1 (RD-)
/Eth-TX-: U101.T-, U501.3 (RD+)
/GPS-EN: J110.1, U101.28 (RX7)
/GPS-PPS: J110.5, U101.29 (TX7)
/GPS-RX: J110.2, U101.0 (RX1)
/GPS-TX: J110.3, U101.1 (TX1)
/I^{2}C-SCL: J109.2, J112.3, U101.19 (A5)
/I^{2}C-SDA: J109.1, J112.2, U101.18 (A4)
/OLED-DC: J111.2, U101.6 (OUT1D)
/OLED-RST: J111.1, U101.7 (RX2)
/PWR-~SHDN: U101.8 (TX2), U401.3 (CE), U402.4 (~SHDN)
/Rot-BTN: SW101.3 (SW), U101.4 (BCLK2)
/Rot-IL: SW101.5 (CLK), U101.3 (LRCLK2)
/Rot-IR: SW101.4 (DT), U101.2 (OUT2)
/SPI-CLK: J111.4, U101.13 (SCK)
/SPI-CS_{1}: J111.3, U101.10 (CS1)
/SPI-M_{O}S_{I}: J111.5, U101.11 (MOSI)
GND: BT401.2 (-), C401.2, C402.2, C403.2, C405.2, C406.2, C407.2, C501.2, D101.1 (A), D101.4 (A), J105.1, J105.3, J105.5, J106.1, J106.3, J106.5, J106.7, J107.1, J107.3, J107.5, J108.1, J108.3, J108.5, J108.7, J109.3, J110.6, J111.6, J112.5, R102.2, R105.2, R106.2, R401.1, SW101.1 (GND), TP401.1, U101.GND1 (GND), U101.GND2 (GND__1), U101.GND3 (GND__2), U101.GND4 (GND__3), U101.GND5 (GND__4), U401.2 (GND), U402.1 (PGND), U402.2 (GND), U501.8, U501.10 (LLED-), U501.12 (RLED-), U501.13 (SHIELD)
unnamed: BZ101.1 (-), R102.1
unnamed: C203.1, C204.1, R201.2, R202.1
unnamed: C205.1, D201.1 (Annode), R202.2
unnamed: C208.1, R204.1, R205.1, U201.2 (-)
unnamed: C209.1, R207.1, R208.1, U202.2 (-)
unnamed: C209.2, C210.1, R208.2, U202.1
unnamed: C303.1, C304.1, R301.2, R302.1
unnamed: C305.1, D301.1 (Annode), R302.2
unnamed: C308.1, R304.1, R305.1, U301.2 (-)
unnamed: C309.1, R307.1, R308.1, U302.2 (-)
unnamed: C309.2, C310.1, R308.2, U302.1
unnamed: C404.2, L401.1, U402.5 (VIN)
unnamed: C405.1, D401.1 (K), R402.2, R403.1
unnamed: C501.1, U501.2 (CT), U501.5 (CT)
unnamed: D202.1 (A), R209.1, R211.1, U201.6 (-)
unnamed: D202.3 (common), U202.7
unnamed: D202.4 (A), R212.1, R213.1, U202.6 (-)
unnamed: D202.6 (common), U201.7
unnamed: D302.1 (A), R309.1, R311.1, U301.6 (-)
unnamed: D302.3 (common), U302.7
unnamed: D302.4 (A), R312.1, R313.1, U302.6 (-)
unnamed: D302.6 (common), U301.7
unnamed: D401.2 (A), L401.2, U402.6 (LX)
unnamed: R105.1, U101.14 (A0), U101.16 (A2)
unnamed: R106.1, U101.39 (A15), U101.41 (A17)
unnamed: R401.2, R402.1, U402.3 (FB)

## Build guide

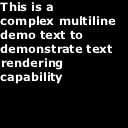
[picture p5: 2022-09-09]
software/arduino/cmake-build-debug/demo.bmp

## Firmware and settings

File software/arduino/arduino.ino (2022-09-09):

//
// Created by nic on 07/08/22.
//

#undef abs
#undef PI

#include "src/graphics/types.h"
#include "src/graphics/algorithms/sdf_generators.h"
#include "src/graphics/algorithms/sdf_transformations.h"
#include "src/graphics/algorithms/sdf_combiantorics.h"
#include "src/graphics/renderer/sdf_mix.h"
#include "src/graphics/renderer/stream_converters.h"
#include "src/graphics/renderer/assets.h"
#include "src/graphics/driver/OLED_1_5INCH_128x128.h"
#include "src/graphics/font/font.h"

#include "data/fonts/verdana/Verdana.ttf.h"
#include "data/fonts/droid-sans/DroidSans.ttf.h"
#include "data/splash/demo.raw.h"

using namespace SDF;

unsigned int height = 128;
unsigned int width = 128;
int iter = 0;
bool iterFlag = false;

float t = 0.5;

OLED_1inch5_128 oled;
FontRenderer fontV[] = { FontRenderer(Verdana_ttf, sizeof(Verdana_ttf), 14), 
                         FontRenderer(Verdana_ttf, sizeof(Verdana_ttf), 13), 
                         FontRenderer(Verdana_ttf, sizeof(Verdana_ttf), 12), 
                         FontRenderer(Verdana_ttf, sizeof(Verdana_ttf), 11) };
FontRenderer fontD[] = { FontRenderer(DroidSans_ttf, sizeof(DroidSans_ttf), 14), 
                         FontRenderer(DroidSans_ttf, sizeof(DroidSans_ttf), 13), 
                         FontRenderer(DroidSans_ttf, sizeof(DroidSans_ttf), 12), 
                         FontRenderer(DroidSans_ttf, sizeof(DroidSans_ttf), 11) };

void calcSDF(int t_) {
    auto* fontArray = fontV;
    if (t_ > 3) {
        fontArray = fontD;
        t_ -= 4;
    }

    auto buffer = PixelBuffer<uint8_t>({ 128u, 128u });
    fontArray[t_].renderTextToBuffer("This is a\n"
                            "complex multiline\n"
                            "text to\n"
                            "demonstrate text\n"
                            "rendering\n"
                            "capability", &buffer);

    auto sdf = SDF::SGrayscale(buffer);
  
    // Create SDF 
    /*auto sdf = MVisualization(
      TTranslate(
        CInterpolate(
          GSegment(vec2(-35.0f), vec2(35.0f), 10.0f),
          TRotate(
             GSegment(vec2(-35.0f), vec2(35.0f), 10.0f), 
           90), 
        t_),
      vec2(64))
    );*/

    auto sdfPixel = SPack565(sdf);

    oled.bake(sdfPixel);
}

void setup() {
  oled = OLED_1inch5_128(6);
  auto splashBuffer = UnsafePixelBuffer<RGB8>({ 128u, 128u }, (RGB8*) demo_raw);
  auto sdfPixel = SPack565(splashBuffer);
  oled.bake(sdfPixel);
  oled.transfer();
  delay(5000);
}

void loop() {
  double timeDrawing = 0;
  double timeTransferring = 0;
  
  
  for (int i = 0; i < 30; i++) {
    // Generate a new Image
    unsigned long startTime = millis();
    
    calcSDF(iter);
    unsigned long drawTime = millis();
    
    oled.transfer();
    unsigned long transferTime = millis();

    timeDrawing += drawTime - startTime;
    timeTransferring += transferTime - drawTime;

    if (iter >= 7)
        iterFlag = true;
    else if (iter <= 0)
        iterFlag = false;
  
    if (iterFlag)
        iter--;
    else
        iter++;
  }
  
  double transferedData = OLED_1in5_RGB_HEIGHT * OLED_1in5_RGB_WIDTH * 2 * 30 / 1000;
  double transferRate = transferedData / timeTransferring * 1000;
  double drawTime = timeDrawing / 30;
  double transferTime = timeTransferring / 30;
  
  Serial.println("Drawing took is: " + String(drawTime) + "ms");
  Serial.println("Transfer rate is: " + String(transferRate) + "kB/s, Transferring took is: " + String(transferTime) + "ms");
}

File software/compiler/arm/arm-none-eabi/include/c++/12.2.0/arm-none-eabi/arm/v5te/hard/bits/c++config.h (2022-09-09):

// Predefined symbols and macros -*- C++ -*-

// Copyright (C) 1997-2022 Free Software Foundation, Inc.
//
// This file is part of the GNU ISO C++ Library.  This library is free
// software; you can redistribute it and/or modify it under the
// terms of the GNU General Public License as published by the
// Free Software Foundation; either version 3, or (at your option)
// any later version.

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
// Under Section 7 of GPL version 3, you are granted additional
// permissions described in the GCC Runtime Library Exception, version
// 3.1, as published by the Free Software Foundation.

// You should have received a copy of the GNU General Public License and
// a copy of the GCC Runtime Library Exception along with this program;
// see the files COPYING3 and COPYING.RUNTIME respectively.  If not, see
// <http://www.gnu.org/licenses/>.

/** @file bits/c++config.h
 *  This is an internal header file, included by other library headers.
 *  Do not attempt to use it directly. @headername{version}
 */

#ifndef _GLIBCXX_CXX_CONFIG_H
#define _GLIBCXX_CXX_CONFIG_H 1

// The major release number for the GCC release the C++ library belongs to.
#define _GLIBCXX_RELEASE 12

// The datestamp of the C++ library in compressed ISO date format.
#define __GLIBCXX__ 20220819

// Macros for various attributes.
//   _GLIBCXX_PURE
//   _GLIBCXX_CONST
//   _GLIBCXX_NORETURN
//   _GLIBCXX_NOTHROW
//   _GLIBCXX_VISIBILITY
#ifndef _GLIBCXX_PURE
# define _GLIBCXX_PURE __attribute__ ((__pure__))
#endif

#ifndef _GLIBCXX_CONST
# define _GLIBCXX_CONST __attribute__ ((__const__))
#endif

#ifndef _GLIBCXX_NORETURN
# define _GLIBCXX_NORETURN __attribute__ ((__noreturn__))
#endif

// See below for C++
#ifndef _GLIBCXX_NOTHROW
# ifndef __cplusplus
#  define _GLIBCXX_NOTHROW __attribute__((__nothrow__))
# endif
#endif

// Macros for visibility attributes.
//   _GLIBCXX_HAVE_ATTRIBUTE_VISIBILITY
//   _GLIBCXX_VISIBILITY
# define _GLIBCXX_HAVE_ATTRIBUTE_VISIBILITY 1

#if _GLIBCXX_HAVE_ATTRIBUTE_VISIBILITY
# define _GLIBCXX_VISIBILITY(V) __attribute__ ((__visibility__ (#V)))
#else
// If this is not supplied by the OS-specific or CPU-specific
// headers included below, it will be defined to an empty default.
# define _GLIBCXX_VISIBILITY(V) _GLIBCXX_PSEUDO_VISIBILITY(V)
#endif

// Macros for deprecated attributes.
//   _GLIBCXX_USE_DEPRECATED
//   _GLIBCXX_DEPRECATED
//   _GLIBCXX_DEPRECATED_SUGGEST( string-literal )
//   _GLIBCXX11_DEPRECATED
//   _GLIBCXX11_DEPRECATED_SUGGEST( string-literal )
//   _GLIBCXX14_DEPRECATED
//   _GLIBCXX14_DEPRECATED_SUGGEST( string-literal )
//   _GLIBCXX17_DEPRECATED
//   _GLIBCXX17_DEPRECATED_SUGGEST( string-literal )
//   _GLIBCXX20_DEPRECATED( string-literal )
//   _GLIBCXX20_DEPRECATED_SUGGEST( string-literal )
#ifndef _GLIBCXX_USE_DEPRECATED
# define _GLIBCXX_USE_DEPRECATED 1
#endif

#if defined(__DEPRECATED)
# define _GLIBCXX_DEPRECATED __attribute__ ((__deprecated__))
# define _GLIBCXX_DEPRECATED_SUGGEST(ALT) \
  __attribute__ ((__deprecated__ ("use '" ALT "' instead")))
#else
# define _GLIBCXX_DEPRECATED
# define _GLIBCXX_DEPRECATED_SUGGEST(ALT)
#endif

#if defined(__DEPRECATED) && (__cplusplus >= 201103L)
# define _GLIBCXX11_DEPRECATED _GLIBCXX_DEPRECATED
# define _GLIBCXX11_DEPRECATED_SUGGEST(ALT) _GLIBCXX_DEPRECATED_SUGGEST(ALT)
#else
# define _GLIBCXX11_DEPRECATED
# define _GLIBCXX11_DEPRECATED_SUGGEST(ALT)
#endif

#if defined(__DEPRECATED) && (__cplusplus >= 201402L)
# define _GLIBCXX14_DEPRECATED _GLIBCXX_DEPRECATED
# define _GLIBCXX14_DEPRECATED_SUGGEST(ALT) _GLIBCXX_DEPRECATED_SUGGEST(ALT)
#else
# define _GLIBCXX14_DEPRECATED
# define _GLIBCXX14_DEPRECATED_SUGGEST(ALT)
#endif

#if defined(__DEPRECATED) && (__cplusplus >= 201703L)
# define _GLIBCXX17_DEPRECATED [[__deprecated__]]
# define _GLIBCXX17_DEPRECATED_SUGGEST(ALT) _GLIBCXX_DEPRECATED_SUGGEST(ALT)
#else
# define _GLIBCXX17_DEPRECATED
# define _GLIBCXX17_DEPRECATED_SUGGEST(ALT)
#endif

#if defined(__DEPRECATED) && (__cplusplus >= 202002L)
# define _GLIBCXX20_DEPRECATED(MSG) [[deprecated(MSG)]]
# define _GLIBCXX20_DEPRECATED_SUGGEST(ALT) _GLIBCXX_DEPRECATED_SUGGEST(ALT)
#else
# define _GLIBCXX20_DEPRECATED(MSG)
# define _GLIBCXX20_DEPRECATED_SUGGEST(ALT)
#endif

// Macros for ABI tag attributes.
#ifndef _GLIBCXX_ABI_TAG_CXX11
# define _GLIBCXX_ABI_TAG_CXX11 __attribute ((__abi_tag__ ("cxx11")))
#endif

// Macro to warn about unused results.
#if __cplusplus >= 201703L
# define _GLIBCXX_NODISCARD [[__nodiscard__]]
#else
# define _GLIBCXX_NODISCARD
#endif



#if __cplusplus

// Macro for constexpr, to support in mixed 03/0x mode.
#ifndef _GLIBCXX_CONSTEXPR
# if __cplusplus >= 201103L
#  define _GLIBCXX_CONSTEXPR constexpr
#  define _GLIBCXX_USE_CONSTEXPR constexpr
# else
#  define _GLIBCXX_CONSTEXPR
#  define _GLIBCXX_USE_CONSTEXPR const
# endif
#endif

#ifndef _GLIBCXX14_CONSTEXPR
# if __cplusplus >= 201402L
#  define _GLIBCXX14_CONSTEXPR constexpr
# else
#  define _GLIBCXX14_CONSTEXPR
# endif
#endif
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

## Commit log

2022-07-28 Version 2.3 commit
    [BOM.ods, CosmicWatch-ventidue.csv, CosmicWatch-ventidue.kicad_pcb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]
2022-07-29 Added gerber files in kicad/plots, both compressed and uncompressed
    [CosmicWatch-ventidue-B_Cu.gbl, CosmicWatch-ventidue-B_Mask.gbs, CosmicWatch-ventidue-B_Paste.gbp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]
2022-08-02 Updated PCB files and added plots
    [CosmicWatch-ventidue-B_Cu.gbl, CosmicWatch-ventidue-B_Cu.gbr, CosmicWatch-ventidue-B_Mask.gbr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]
2022-08-17 Push to version 3.3
    [CosmicWatch-ventidue.csv, CosmicWatch-ventidue.kicad_sch, detector.kicad_sch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]
2022-09-05 Updated PCB Images
2022-09-05 Updated KiCAD plots
    [CosmicWatch-ventidue-B_Cu.gbl, CosmicWatch-ventidue-B_Cu.gbr, CosmicWatch-ventidue-B_Mask.gbr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]
2022-09-05 Some generic include fixes
    [OLED_1_5INCH_128x128.h]
2022-09-05 New widget API and first widget, a button
2022-09-05 New plot files
    [CosmicWatch-ventidue-B_Cu.gbr, CosmicWatch-ventidue-B_Mask.gbr, CosmicWatch-ventidue-B_Paste.gbr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]
2022-09-09 New text renderer. New SiPM footprint. Included c++20 compiler.
    [CosmicWatch-ventidue.csv]
